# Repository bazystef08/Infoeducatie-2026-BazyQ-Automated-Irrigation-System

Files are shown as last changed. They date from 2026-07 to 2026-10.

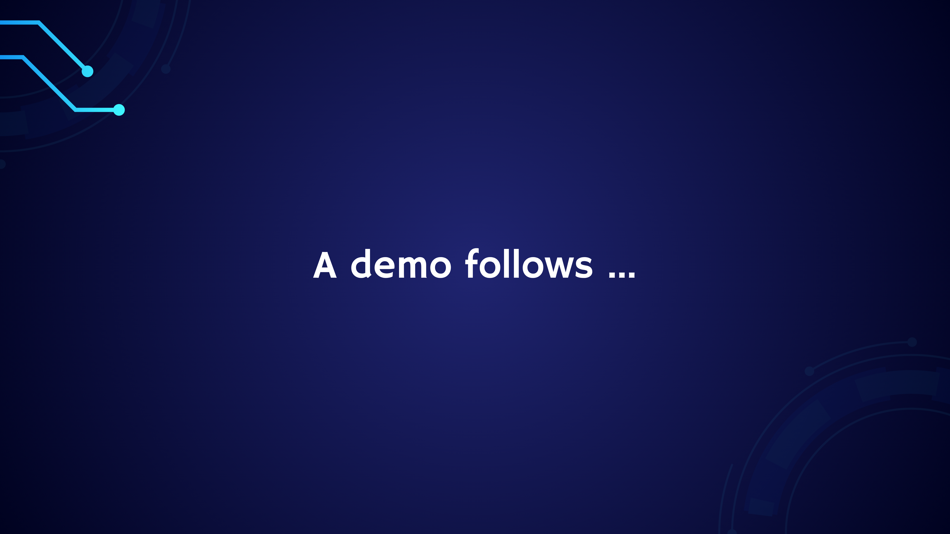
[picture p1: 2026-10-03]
PPT/5.png

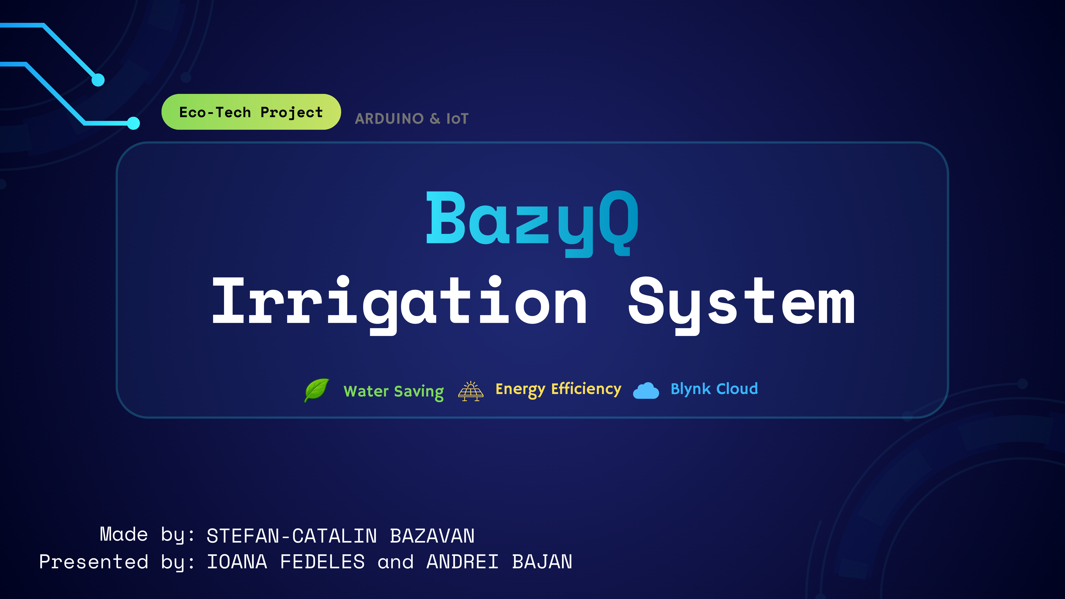
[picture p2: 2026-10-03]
PPT/1.png

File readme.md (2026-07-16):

BazyQ – Automated Irrigation System

BazyQ este un sistem inteligent și autonom de monitorizare și irigare de precizie, conceput pentru a optimiza consumul de resurse și a asigura microclimatul ideal pentru plante. Proiectat în jurul unei arhitecturi hardware robuste și integrat cu tehnologia IoT Blynk, sistemul oferă utilizatorului informații reale, oriunde în lume.
Este un proiect simplu ca idee, dar smart ca implementare și eficient în viața cotidiană.

Pentru a asigura o funcționare stabilă, autonomie energetică și o interfață intuitivă, proiectul BazyQ folosește următoarele componente:
* Arduino UNO R4 Wi-Fi - nucleul proiectului, îmbinând performanțele ridicate cu conectivitatea Wi-Fi nativă pentru gestionarea platformei IoT Blynk
* Senzor Higrometru Capacitiv pentru Umiditatea Solului - durabilitate și rezistență crescută la coroziune, oferind rezultate precise
* Senzor de Temperatură și Umiditate a Aerului (DHT11)
* Senzor Ultrasonic (HC-SR04) - măsoară inteligent nivelul de umplere al rezervorului
* Mini-Pompă Submersibilă (12V)
* Driver MOSFET (Modul IRF520) - gestionează în siguranță componentele externe alimentate la 12V (pompa și ventilatorul exterior)
* Panou Solar - asigură independența energetică a sistemului (NU A POMPEI)
* 2 Acumulatori Li-ion 18650 + Suport
* Modul de Încărcare Litiu 2S (cu funcție de echilibrare - BMS)
* Display OLED 1.3 inch (SH1106) - înlocuiește clasicul ecran LCD, oferind un contrast remarcabil și grafică modernă
* Buton Metalic cu inel LED (fără reținere) - comutarea între modurile AUTO / MANUAL
* Buton cu reținere pentru Alimentare (ON / OFF)
* Ventilator 12V - asigură Aerisirea corespunzătoare a Carcasei
* Elemente Printate 3D - No colour, No Flavour!
Codul a fost realizat în mediul de programare Arduino IDE.

Cerințe:
* conexiune stabilă la internet pentru funcționarea platformei IoT Blynk și monitorizarea parametrilor
* priză pentru conectarea sursei de alimentare a pompei 12V
* plantă
* apă

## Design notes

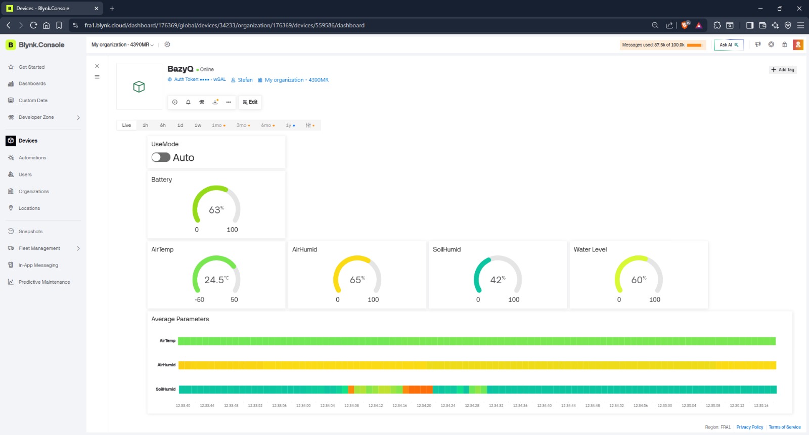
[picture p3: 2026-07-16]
Robot Photos/Blynk.jpeg

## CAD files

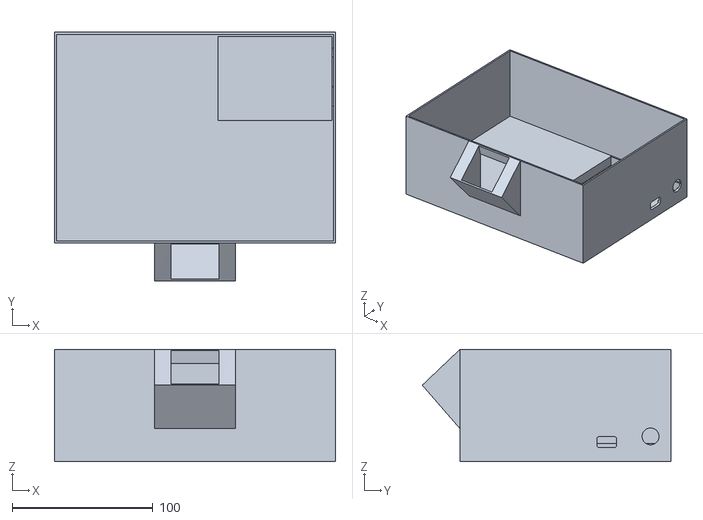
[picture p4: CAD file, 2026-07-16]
3D Components/Cutie.stl
200.0 x 176.9 x 80.0

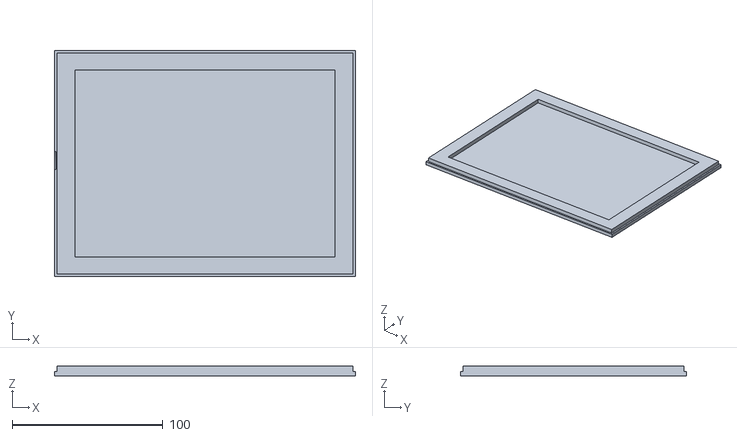
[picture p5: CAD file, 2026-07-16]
3D Components/Capac Cutie.stl
200.0 x 150.0 x 6.50

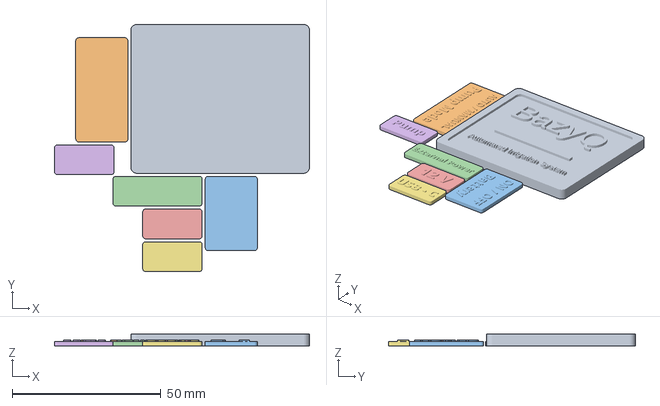
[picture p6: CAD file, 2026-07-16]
3D Components/Etichete.3mf
85.6 x 83.0 x 4.00 mm
Parametric_Model_Maker_1 x 7

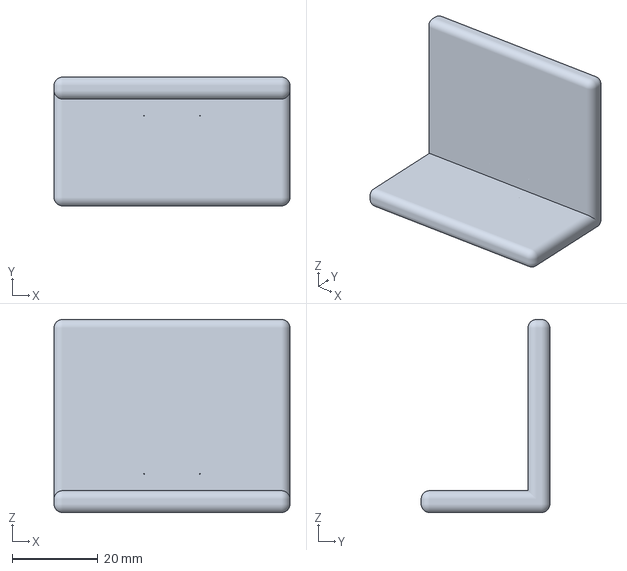
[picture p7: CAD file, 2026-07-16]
3D Components/Suport Pompa.3mf
55.0 x 30.0 x 45.0 mm

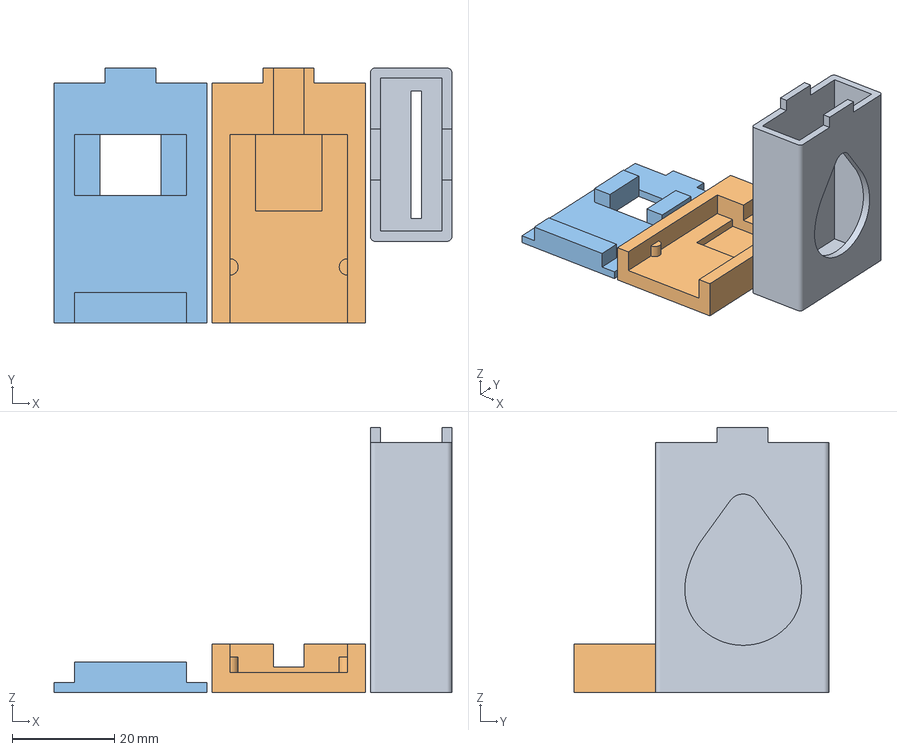
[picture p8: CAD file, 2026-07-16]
3D Components/Capac Senzor Umid.3mf
78.0 x 50.0 x 52.0 mm
sensor_lid_final.step
sensor_inlay_a.step
sensor_inlay_b.step

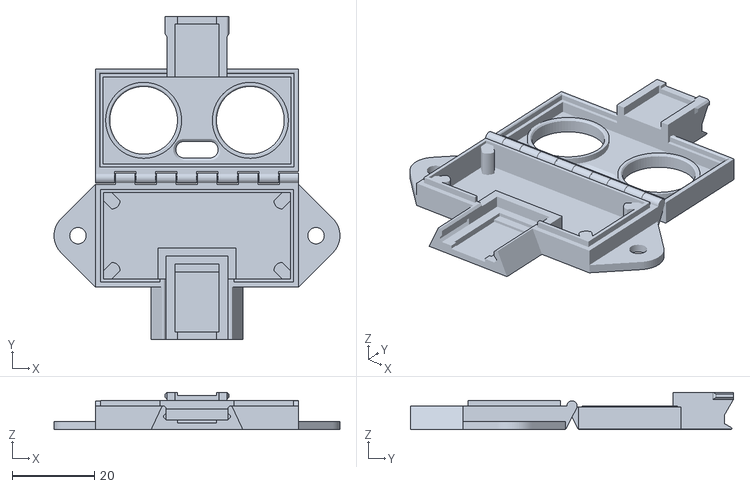
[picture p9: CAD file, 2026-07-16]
3D Components/Suport HC-SR04.stl
69.7 x 78.7 x 9.10

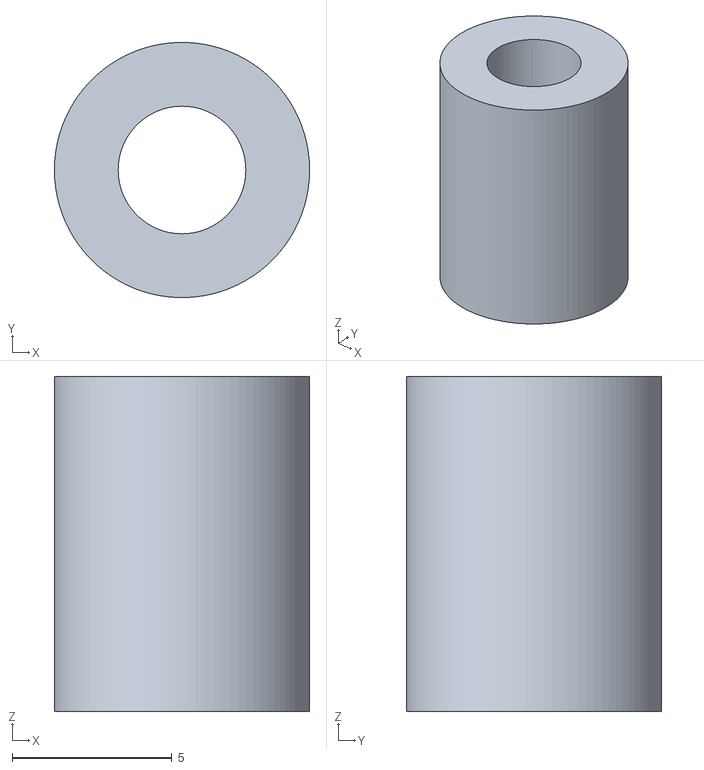
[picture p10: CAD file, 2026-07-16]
3D Components/Distantier.stl
8.00 x 8.00 x 10.5

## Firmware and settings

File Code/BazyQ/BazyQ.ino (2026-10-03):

#include <Arduino.h>
#include <Wire.h>
#include <U8g2lib.h>
#include <DHT.h>

U8G2_SH1106_128X64_NONAME_F_HW_I2C u8g2(U8G2_R0, U8X8_PIN_NONE);

#define BLYNK_TEMPLATE_ID "TMPL4mFYbqtY0"
#define BLYNK_TEMPLATE_NAME "BazyQ"
#define BLYNK_AUTH_TOKEN "HuFEI2zsFufmI8RQUlI_e3-wstvVwSAL"
#include <BlynkSimpleWifi.h>
BlynkTimer timer;
const char* ssid = "BZY WIFI BUC";
const char* password = "Bazy1977";

#define SOIL_PIN A0
const int dry = 750; 
const int wet = 320;

#define BATTERY_PIN A1

#define DHTPIN 2
#define DHTTYPE DHT11
DHT dht(DHTPIN, DHTTYPE);

#define PUMP_PIN 3

#define BUTTON_PIN 4
#define LED_PIN 5
bool UseMode = false; // False - Auto ; True - Manual ;

#define TRIG_PIN 6
#define ECHO_PIN 7
bool notif = false;
int water;

void WriteCentered(const char* text, int y)
{
  int textwidth = u8g2.getStrWidth(text);
  int x = (128 - textwidth) / 2;
  u8g2.drawStr(x, y, text);
}

BLYNK_WRITE(V1)
{
  if (param.asInt() == 1) UseMode = true;
  else UseMode = false;
  digitalWrite(LED_PIN, UseMode);
}

void SendDataToBlynk()
{
  Blynk.virtualWrite(V1, UseMode ? 1 : 0);
  Blynk.virtualWrite(V2, dht.readTemperature());
  Blynk.virtualWrite(V3, dht.readHumidity());
  Blynk.virtualWrite(V4, Soil());
  Blynk.virtualWrite(V5, water);
  Blynk.virtualWrite(V6, Battery());
}

int Soil()
{
  int SoilPercent = constrain(map(analogRead(SOIL_PIN), dry, wet, 0, 100), 0, 100);
  return SoilPercent;
}

int WaterLevel()
{
  digitalWrite(TRIG_PIN, LOW);
  delayMicroseconds(5);
  digitalWrite(TRIG_PIN, HIGH);
  delayMicroseconds(10);
  digitalWrite(TRIG_PIN, LOW);
  long duration = pulseIn(ECHO_PIN, HIGH, 25000);
  int cm = duration * 0.0343 / 2;
  if(cm >= 50) return 0;
  else
  {
    int waterDist = constrain(map(cm, 12, 2, 0, 100), 0, 100);
    return waterDist;
  } 
}

int Battery()
{
  int rawBat = analogRead(BATTERY_PIN);
  double vBat = (rawBat * 5.0 / 1023.0) * 5.0;
  int batPct = constrain(map(vBat * 100, 600, 840, 0, 100), 0, 100);
  return batPct;
}

void setup()
{
  Serial.begin(9600);
  u8g2.begin();
  u8g2.setI2CAddress(0x3C * 2);
  u8g2.setFont(u8g2_font_ncenB08_tr); 

// Custom Intro Message
  u8g2.clearBuffer();
  WriteCentered("BazyQ", 15);
  WriteCentered("Avem curent!", 35);
  WriteCentered("Arduino Uno R4 WIFI", 55);
  u8g2.sendBuffer();

// Air Temp and Humid
  dht.begin();

// Soil Humid
  pinMode(SOIL_PIN, INPUT);

// Pump
  pinMode(PUMP_PIN, OUTPUT);
  digitalWrite(PUMP_PIN, LOW);

// AUTO / MANUAL Button and LED
  pinMode(BUTTON_PIN, INPUT_PULLUP);
  pinMode(LED_PIN, OUTPUT);
  digitalWrite(LED_PIN, LOW);

// HC-SR04 Sensor
  pinMode(TRIG_PIN, OUTPUT);
  pinMode(ECHO_PIN, INPUT);

  delay(5000);
  
// Connect Blynk
  u8g2.clearBuffer();
  WriteCentered("Conectare Blynk...", 35);
  u8g2.sendBuffer();
  Blynk.config(BLYNK_AUTH_TOKEN);
  WiFi.begin(ssid, password);
  timer.setInterval(1000L, SendDataToBlynk);

  delay(1000);
}

void loop()
{
  if (WiFi.status() == WL_CONNECTED) Blynk.run();
  timer.run();

  water = WaterLevel();

  if(water <= 15)
  {
    digitalWrite(PUMP_PIN, LOW);
    
    Blynk.logEvent("rezervor_gol", "Alerta: Rezervorul BazyQ este gol! Umpleti vasul.");
    notif = true;

    u8g2.clearBuffer();

    u8g2.drawRFrame(5, 5, 118, 54, 4);
    u8g2.drawRFrame(7, 7, 114, 50, 2);
    u8g2.setFont(u8g2_font_ncenB10_tr);
    WriteCentered("ALERTA!", 25);
    u8g2.setFont(u8g2_font_ncenB08_tr);
    WriteCentered("REZERVOR GOL", 40);
    WriteCentered("Umpleti vasul!", 52);

    u8g2.sendBuffer();
  }
  else
  {
    notif = false;
    u8g2.clearBuffer();

    u8g2.setCursor(0, 15);
    if (Blynk.connected()) u8g2.print("Blynk: CONECTAT");
    else u8g2.print("Blynk: OFFLINE");

    u8g2.setCursor(0, 30);
    u8g2.print("AirTemp: ");
    u8g2.print(dht.readTemperature(), 1);
    u8g2.print(" C");

    u8g2.setCursor(0, 45);
    u8g2.print("AirHumid: ");
    u8g2.print(dht.readHumidity(), 1);
    u8g2.print(" %");

    u8g2.setCursor(0, 60);
    u8g2.print("SoilHumid: ");
    u8g2.print(Soil(), 1);
    u8g2.print(" %");

    int barWidth = map(Battery(), 0, 100, 0, 18);
    if (barWidth > 0)
    {
      u8g2.drawRFrame(98, 20, 22, 11, 2);
      u8g2.drawBox(120, 23, 2, 5);
      u8g2.drawBox(100, 22, barWidth, 7);
    }
    else
    {
      u8g2.drawRFrame(93, 20, 28, 13, 2);
      u8g2.drawBox(120, 23, 2, 5);
      u8g2.setCursor(95, 30);
      u8g2.print("USB");
    }

    u8g2.sendBuffer();

    if(UseMode) digitalWrite(PUMP_PIN, HIGH);
    else
    {
      if (Soil() < 50) digitalWrite(PUMP_PIN, HIGH);
      else digitalWrite(PUMP_PIN, LOW);
    }

  }

  if (digitalRead(BUTTON_PIN) == LOW)
  {
    UseMode = !UseMode;
    digitalWrite(LED_PIN, UseMode);
    while(digitalRead(BUTTON_PIN) == LOW) delay(10);
    delay(50);
  }

  delay(1000);
}
